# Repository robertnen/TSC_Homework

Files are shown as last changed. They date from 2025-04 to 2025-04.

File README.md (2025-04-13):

### Nenciu George-Robert 333CC

# TSC_Homework
## Schema pe scurt
<div align="center">
  
</div>
<br>

## Imaginea 3D 
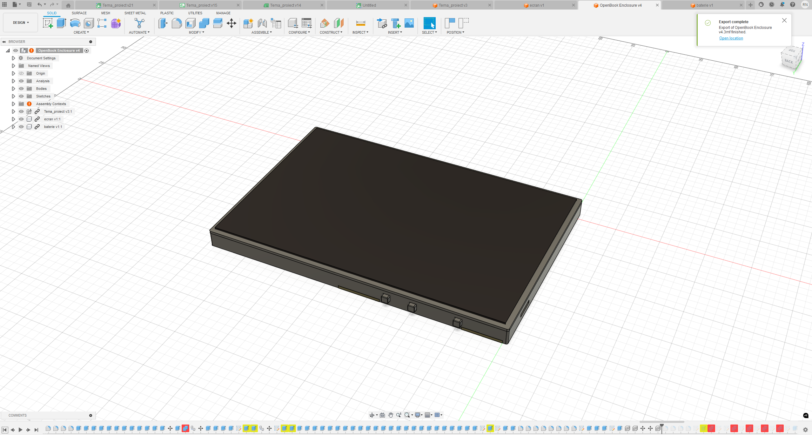
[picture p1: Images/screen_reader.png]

<br>

# Conexiuni Hardware - Proiect ESP32-C6

## ESP32-C6-WROOM-1-N8 (Microcontroler Principal)
- Interfețe disponibile: SPI, I2C, UART, GPIO

---

## BME688 (Senzor Ambiental)
- Interfață: I2C  
- **Pini utilizați**:  
  - SDA → IO21  
  - SCL → IO22

---

## DS3231SN (Real-Time Clock)
- Interfață: I2C (partajat cu BME688)  
- **Pini utilizați**:  
  - SDA → IO21  
  - SCL → IO22  
  - INT_RTC → IO8  
  - 32KHZ → IO1  
  - RTC_RST → IO18

---

## Afișaj E-Ink (7.5 inch)
- Interfață: SPI  
- Rezoluție: 800 x 480 px  
- **Pini utilizați**:  
  - EPD_CS → IO10  
  - EPD_DC → IO5  
  - EPD_RST → IO23  
  - EPD_BUSY → IO3 *(partajat cu MISO)*  
  - MOSI, SCK *(partajate cu SD)*

---

## Modul SD Card
- Interfață: SPI  
- **Pini utilizați**:  
  - SS_SD → IO4  
  - MOSI → IO7  
  - MISO → IO2  
  - SCK → IO6

---

## Memorie Externă Flash (W25Q512JVEIQ, 64MB)
- Interfață: SPI  
- **Pini utilizați**:  
  - FLASH_CS → IO12  
  - MOSI, MISO, SCK *(partajate cu SD)*

---

## Interfață USB/SD
- Funcții: alimentare + date  
- **Pini utilizați**:  
  - USB_D+ → IO13  
  - USB_D- → IO12

---

## Butoane Boot și Reset
- **Pini utilizați**:  
  - IO/BOOT → IO9  
  - RESET → pin dedicat *(conform schemei)*

---

## Sistem de Alimentare și Management
- Baterie Li-Po: 3.7V, 2500mAh  
- **Module și pini**:
  - MCP73831 → încărcare prin USB-C  
  - MAX17048 → monitorizare baterie  
    - SDA → IO21  
    - SCL → IO22  
  - XC6220A331MR-G → 3.3V stabilizat

---

## Conector USB-C
- Funcții: alimentare principală și transfer de date  
- Protejat ESD

---

## Conector Qwiic / Stemma QT
- Interfață: I2C  
- **Pini utilizați**:
  - SDA → IO21  
  - SCL → IO22

<p>ESP32-C6 are un consum de energie optimizat pentru aplicații IoT. În modul activ, consumul variază în funcție de sarcină, dar poate fi redus semnificativ în modurile de repaus profund. De exemplu, în modul Deep Sleep, consumul poate fi de ordinul microamperilor, ceea ce permite o durată de viață extinsă a bateriei.</p>

### Notă privind erorile Airwire / Air Wire

În cadrul designului hardware, anumite erori de tip **Airwire** au fost acceptate intenționat în schema/PCB. Acestea reprezintă conexiuni logice nefinalizate în layout-ul plăcii, dar au fost tolerate în scopuri de testare, dezvoltare rapidă sau în situații unde conexiunile sunt realizate manual (ex: prin fire externe sau jumperi în faza de prototipare). 

Decizia de a le păstra a fost luată pentru a permite flexibilitate în modificări ulterioare și pentru a grăbi ciclul de iterație fără a compromite funcționalitatea de bază a sistemului.

## Alte considerații

<p>În proiectare, s-a ținut cont de recomandările din ghidul de design hardware pentru ESP32-C6 , asigurându-se că traseele PCB pentru interfața I2C sunt cât mai scurte și ecranate corespunzător pentru a minimiza interferențele. De asemenea, s-a acordat atenție alimentării corecte a senzorului BME680, conform specificațiilor acestuia.

Pentru o integrare eficientă a componentelor și optimizarea performanței, s-au urmat recomandările din documentația oficială a ESP32-C6 și a componentelor asociate.</p>

| Componentă | Nr. bucăți | Nume material | Link către datasheet |
|---|---|---|---|
| EAGLE-LTSPICE_C0402 | 26 | Discrete Component | https://eu.mouser.com/datasheet/2/447/KEM_C1023_X7R_AUTO_SMD-3316698.pdf |
| ESP32_WROVER_AVX---SD0805S020S1R0_AVX_SD0805S020S1R0_0 | 2 | Discrete Component | https://eu.mouser.com/datasheet/2/40/AutoMLCCKAM-3216307.pdf |
| ESP32_WROVER_EAGLE-LTSPICE_R0402 | 22 | Discrete Component | https://eu.mouser.com/datasheet/2/54/cr-1858361.pdf |
| TP20R | 17 | Discrete Component | https://www.koaspeer.com/pdfs/RN73R.pdf |
| ESP32_WROVER_SPARKFUN-IC-POWER_SOT23-5 | 1 | Discrete Component | https://eu.mouser.com/datasheet/2/891/Espressif_Systems_ESP32_WROVER_E_L_0-3049094.pdf |
| ADAFRUIT_CHIP-LED0603 | 1 | Discrete Component | https://www.vishay.com/doc?82437 |
| ESP32_WROVER_BME680_PSON80P300X300X100-8N | 1 | Discrete Component | https://eu.mouser.com/datasheet/2/783/BST_BME680_DS001-1509608.pdf |
| ESP32C6_VARISTOR_CT/CN1812 | 1 | Discrete Component | https://product.tdk.com/system/files/dam/doc/product/protection/voltage/varistor_ctvs/data_sheet/75/db/ctvs_14/ct1210s14bautogx1.pdf |
| DIOC1608X36N | 6 | Discrete Component | https://eu.mouser.com/datasheet/2/802/1703143356438-3483895.pdf |
| SOT95P280X120-5N | 1 | Discrete Component | https://www.onsemi.com/PowerSolutions/product.do?id=MC74VHC1GT32P5T5G |
| CAPCP3225X100N | 1 | Discrete Component | https://eu.mouser.com/datasheet/2/18/2/CAP_CACFSBA1-3557832.pdf |
| RCL_CT3528 | 1 | Discrete Component | https://www.vishay.com/doc?20046 |
| ESP32_WROVER_SPARKFUN-DISCRETESEMI_SOT23-3 | 2 | Discrete Component | https://eu.mouser.com/datasheet/2/891/Espressif_Systems_ESP32_WROVER_E_L_0-3049094.pdf |
| SAMACSYS_PARTS_USB4110GFA | 1 | Discrete Component | https://eu.mouser.com/datasheet/2/837/GCT_USB4120-3159195.pdf |
| JST04_1MM_RA | 1 | Discrete Component | https://eu.mouser.com/datasheet/2/564/eCPT-3475515.pdf |
| SOIC127P1032X265-16N | 1 | Discrete Component | https://www.ti.com/lit/ug/sbou289/sbou289.pdf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 |
| XCVR_ESP32-C6-WROOM-1-N8 | 1 | Discrete Component | https://eu.mouser.com/datasheet/2/891/esp32_c6_datasheet_en-3304070.pdf |
| SOT95P280X145-6N | 1 | Discrete Component | https://eu.mouser.com/datasheet/2/414/DIV23-3532318.pdf |
| SOT95P280X125-5N | 1 | Discrete Component | https://eu.mouser.com/datasheet/2/414/DIV23-1551440.pdf |
| FH34SRJ24S05SH99 | 1 | Discrete Component | https://eu.mouser.com/datasheet/2/833/cherry_Rocker_SR_Round_EN-1275415.pdf |
| SON127P600X800X80-9N | 1 | Discrete Component | https://www.ti.com/lit/gpn/tps63710 |
| 16-soldermask | 1 | Steel | https://eu.mouser.com/datasheet/2/58/BPS-DAT-(BB3U)-Datasheet-1282462.pdf |

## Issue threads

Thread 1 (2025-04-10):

Titlul proiectului în schematic depășește chenarul

robertnen, 2025-04-10:
Fișierul cu probleme este:
- [E-Book_v26.sch](https://github.com/stefan-dascalu/Proiect-TSC/blob/main/Hardware/E-Book_v26.sch)

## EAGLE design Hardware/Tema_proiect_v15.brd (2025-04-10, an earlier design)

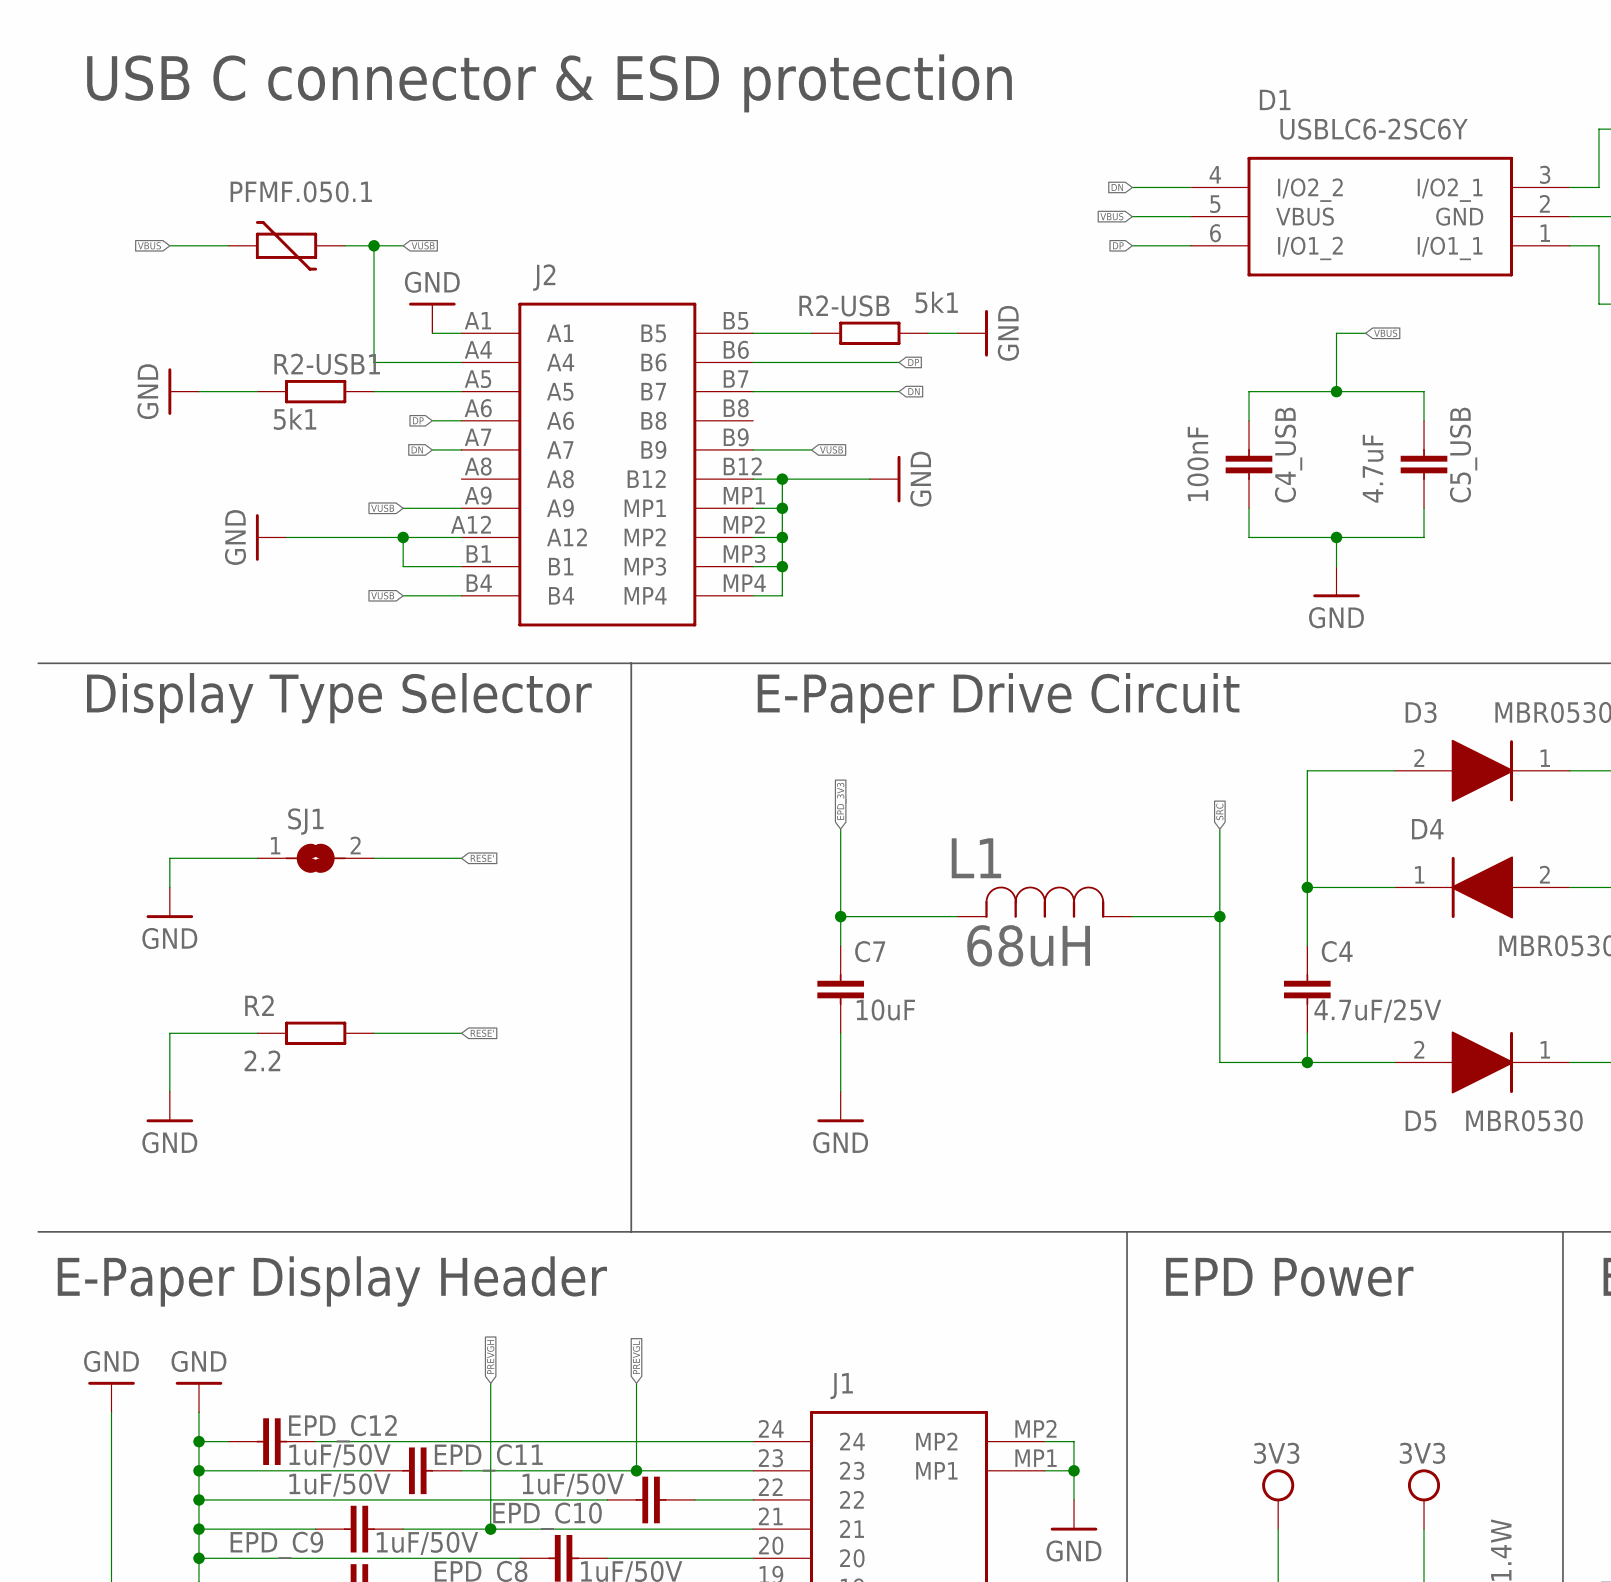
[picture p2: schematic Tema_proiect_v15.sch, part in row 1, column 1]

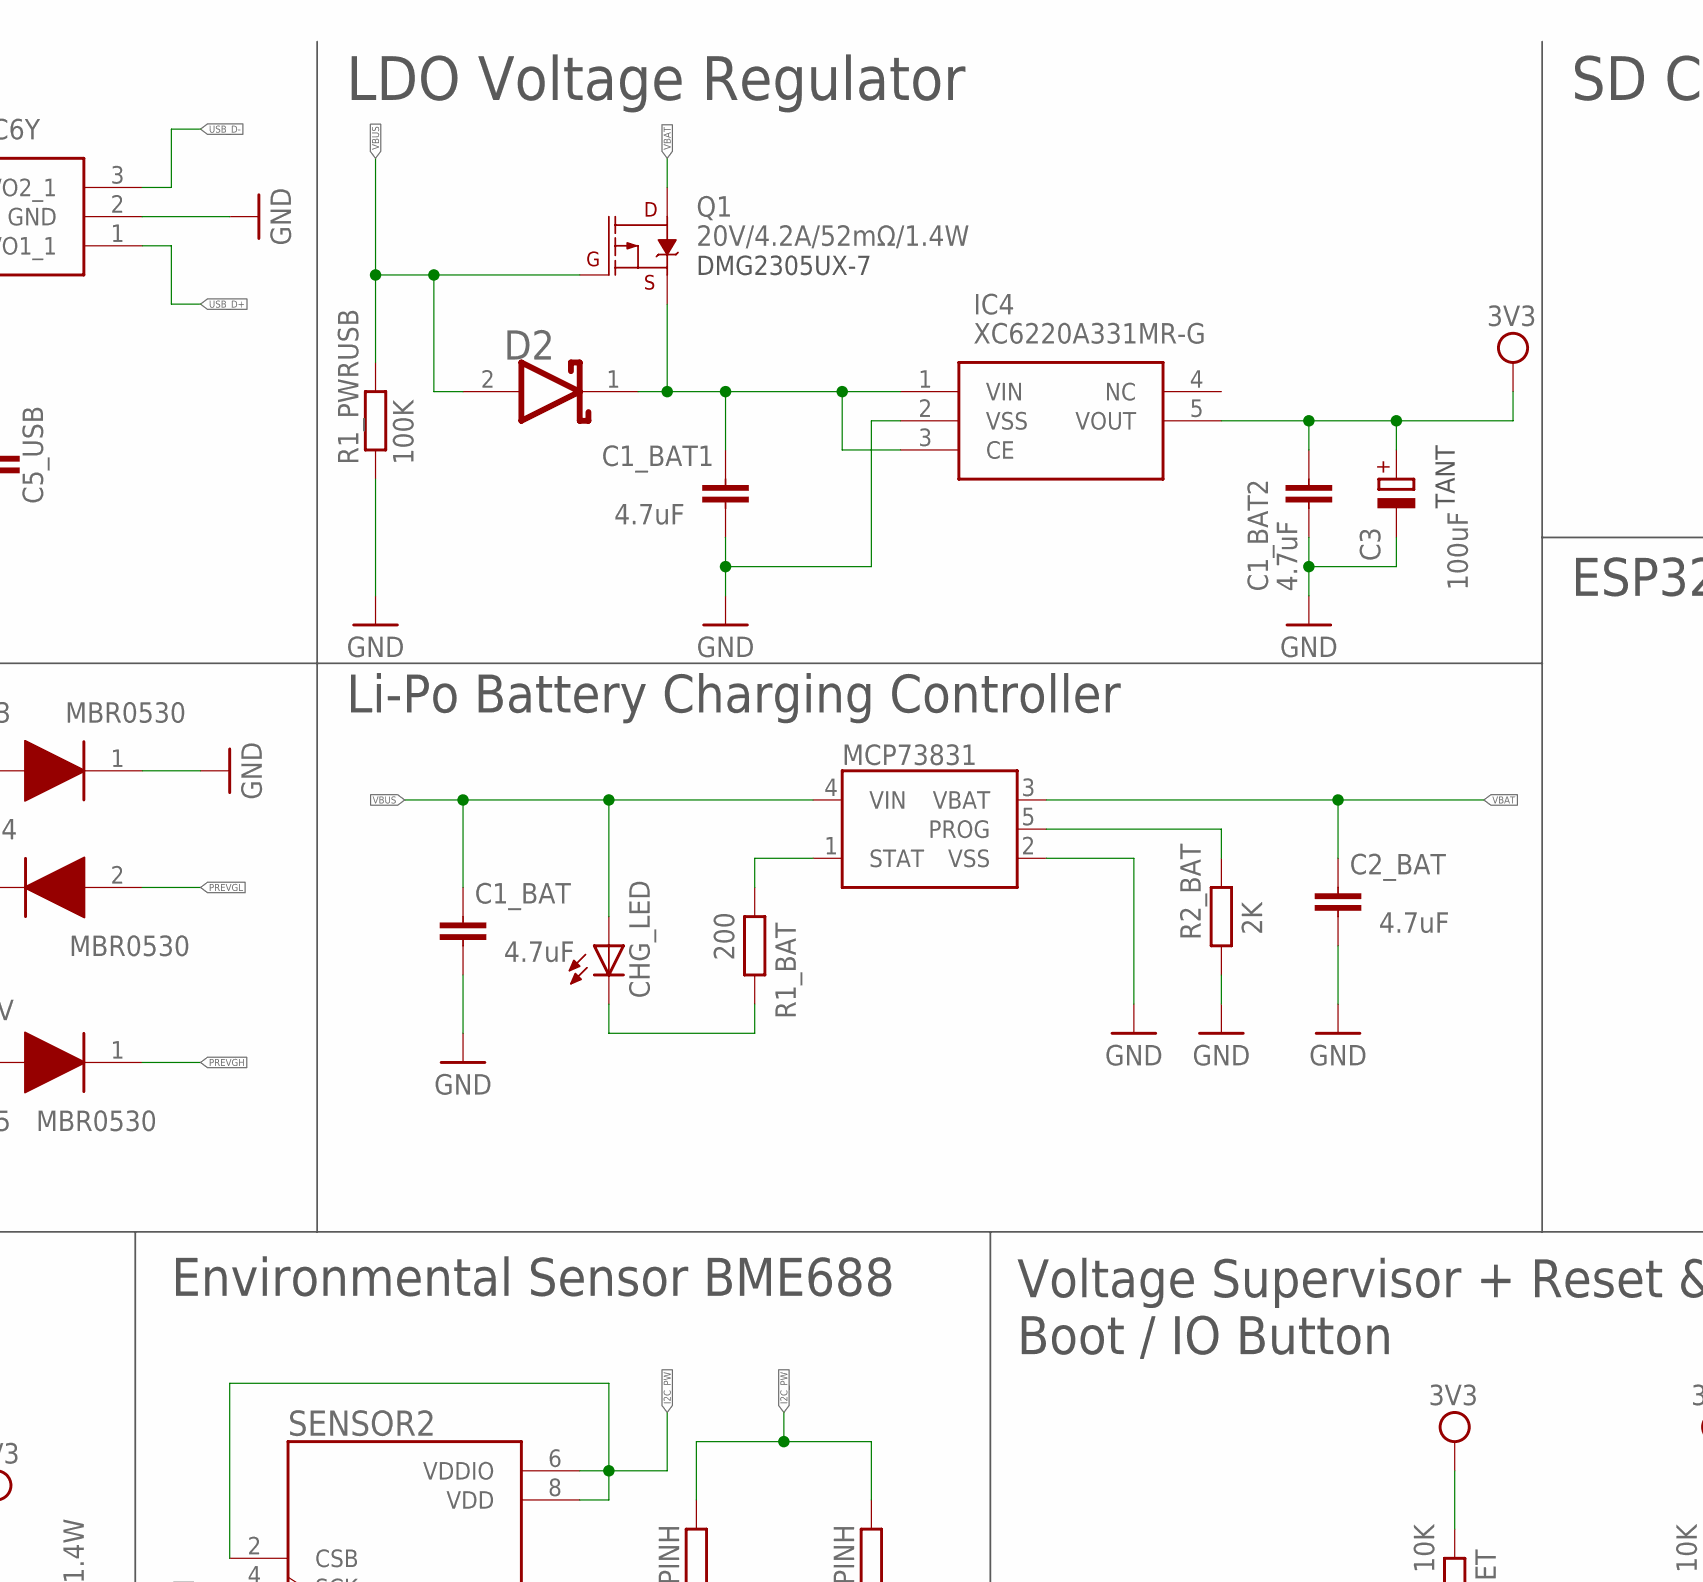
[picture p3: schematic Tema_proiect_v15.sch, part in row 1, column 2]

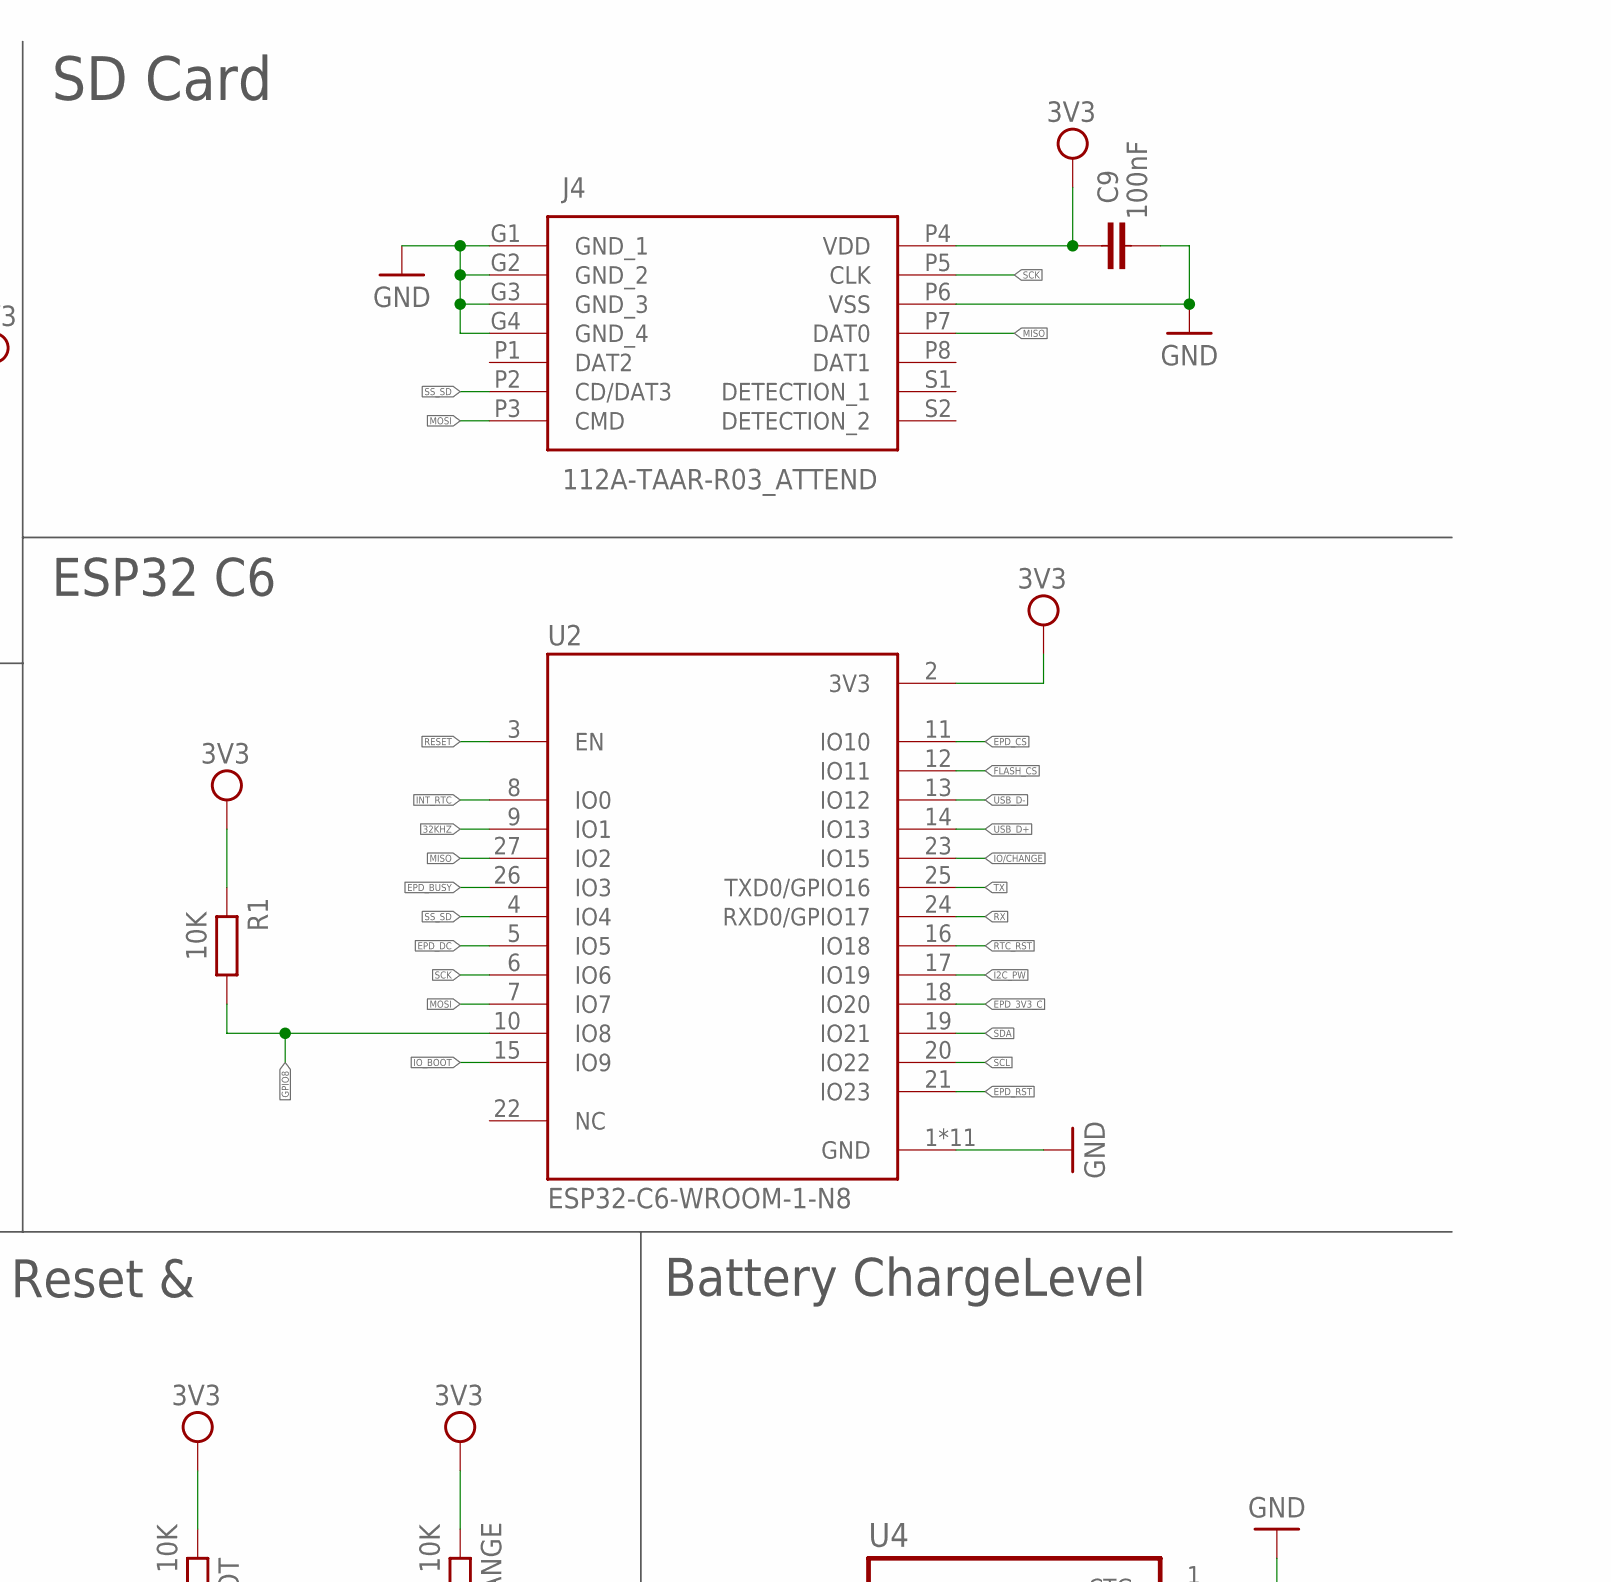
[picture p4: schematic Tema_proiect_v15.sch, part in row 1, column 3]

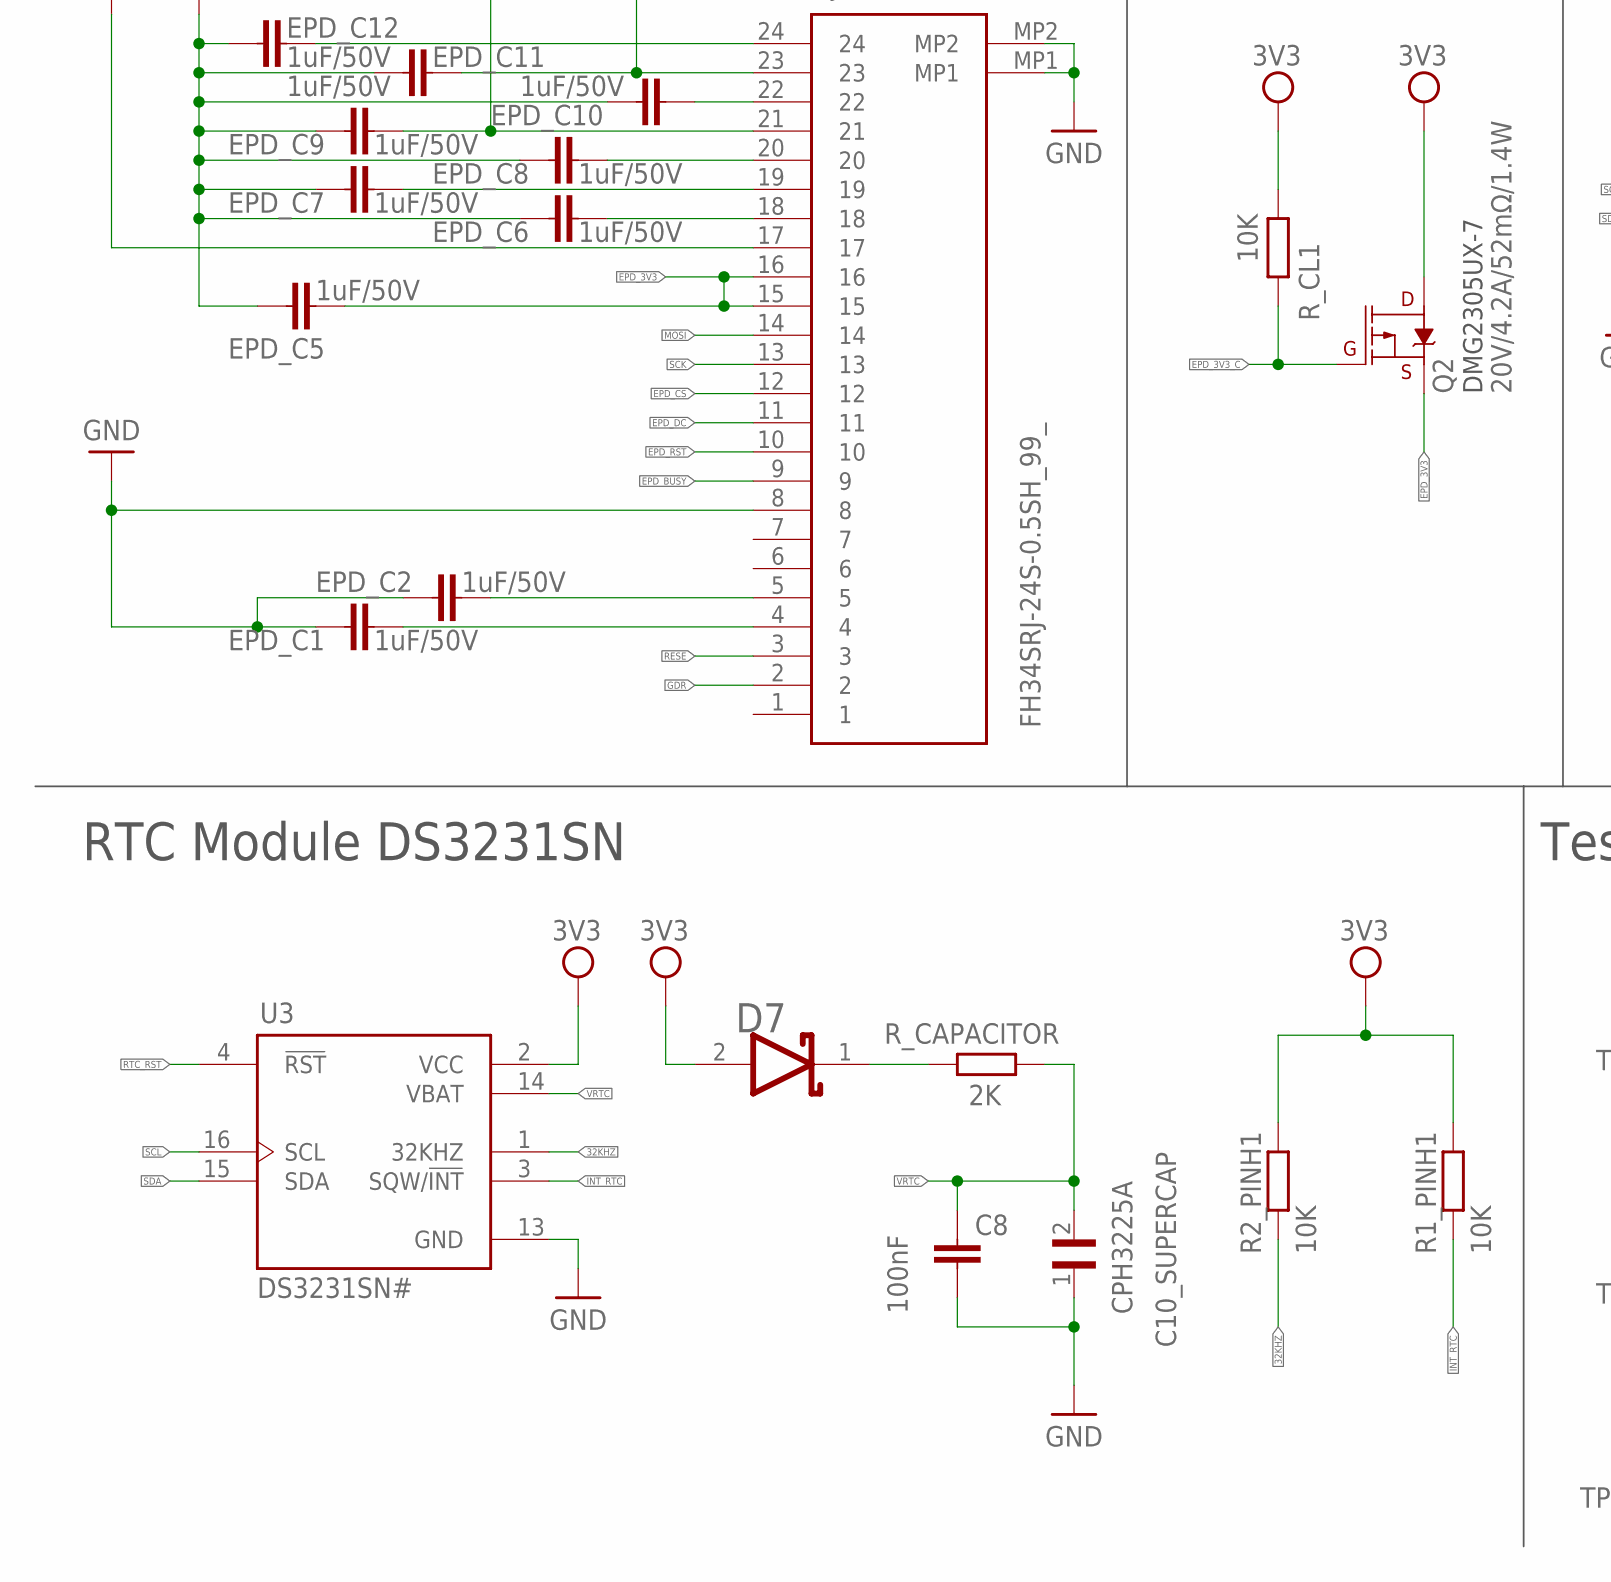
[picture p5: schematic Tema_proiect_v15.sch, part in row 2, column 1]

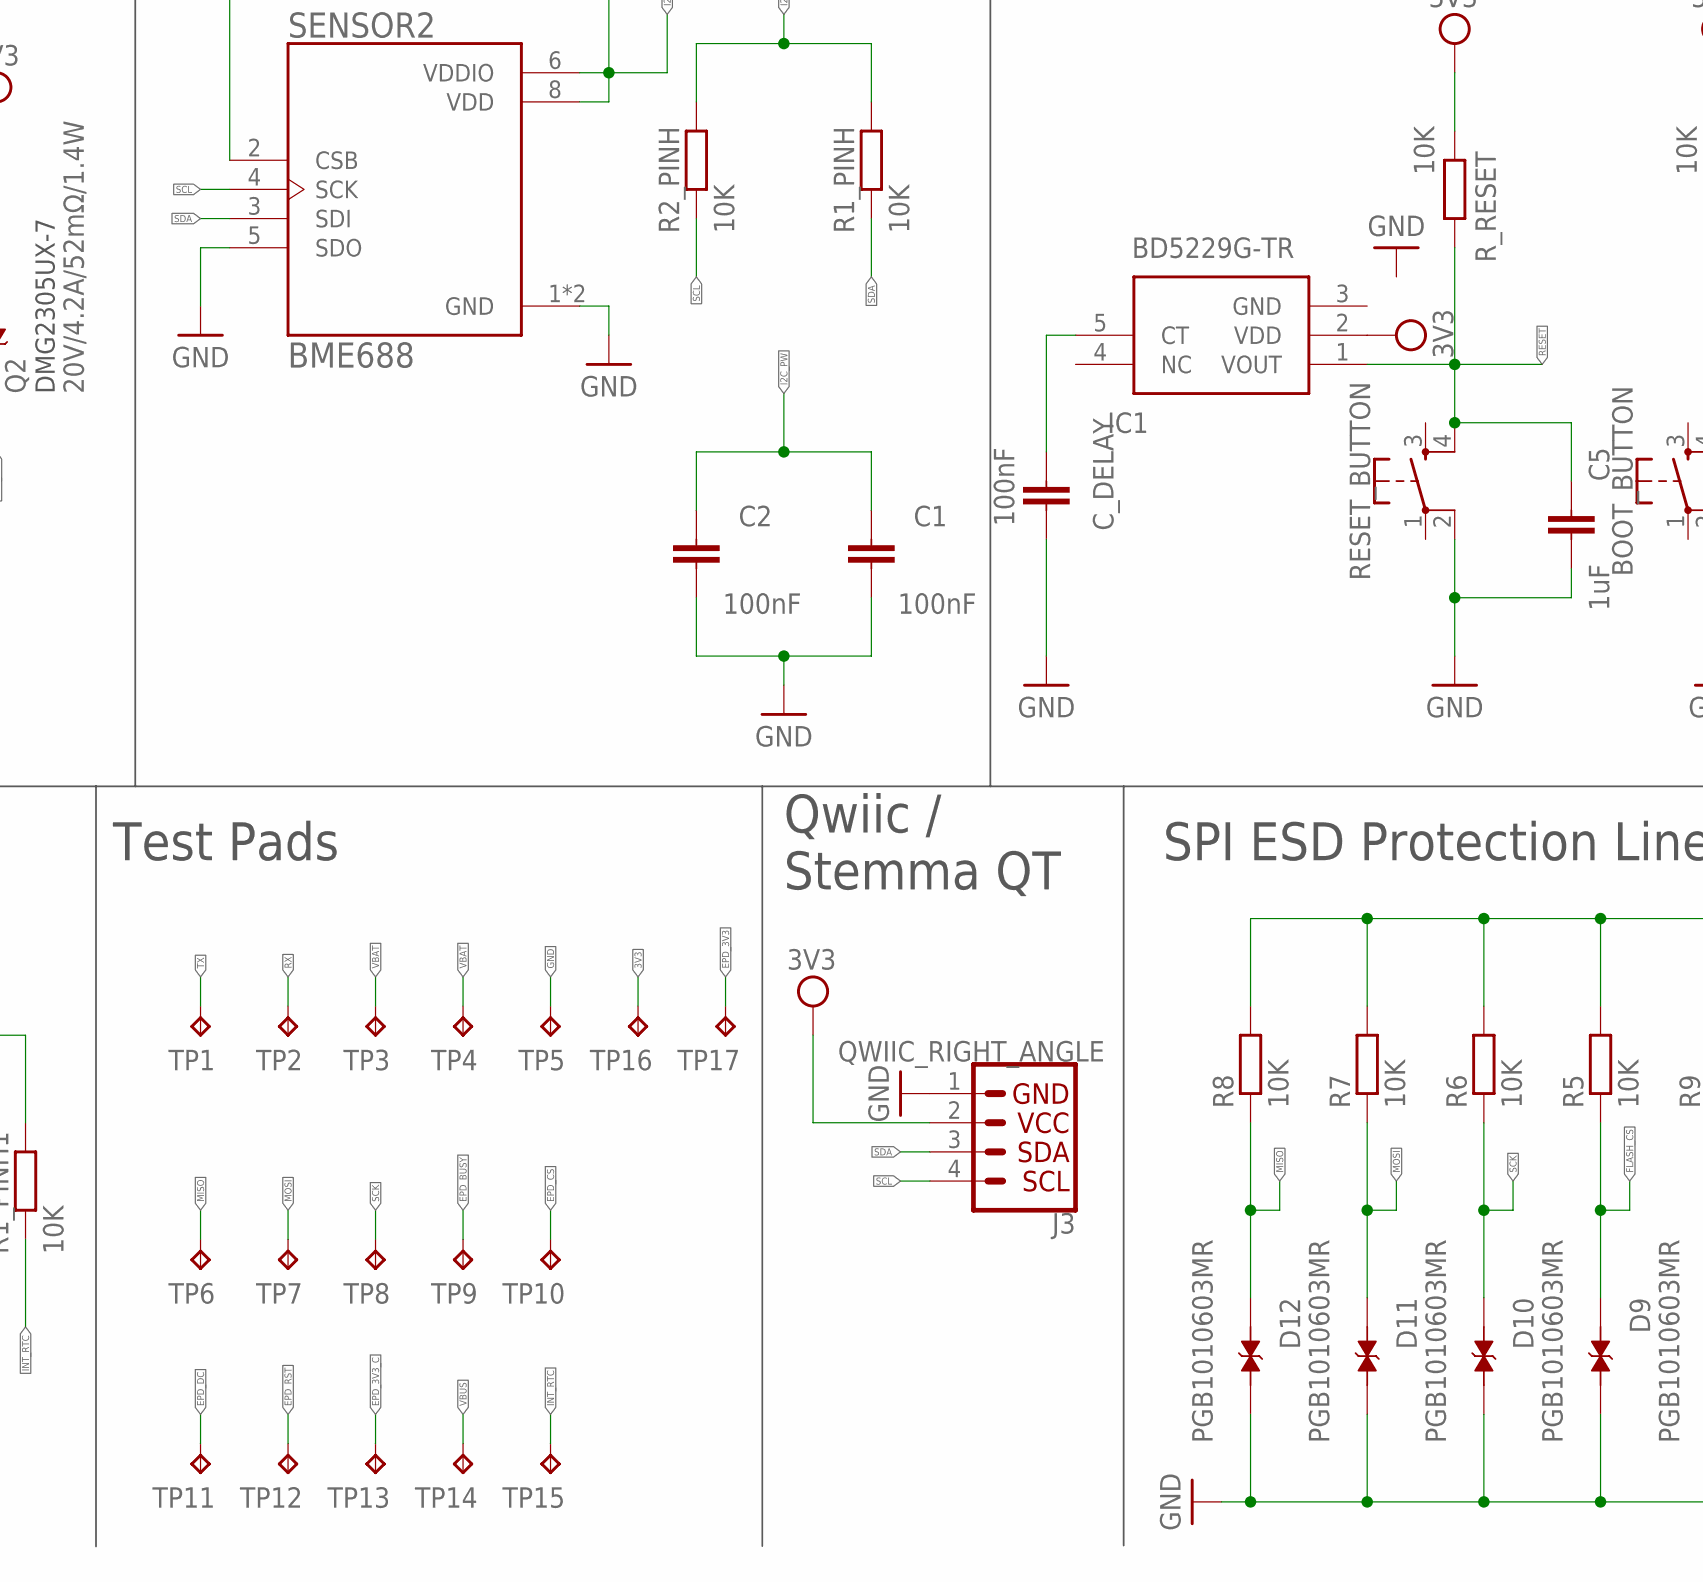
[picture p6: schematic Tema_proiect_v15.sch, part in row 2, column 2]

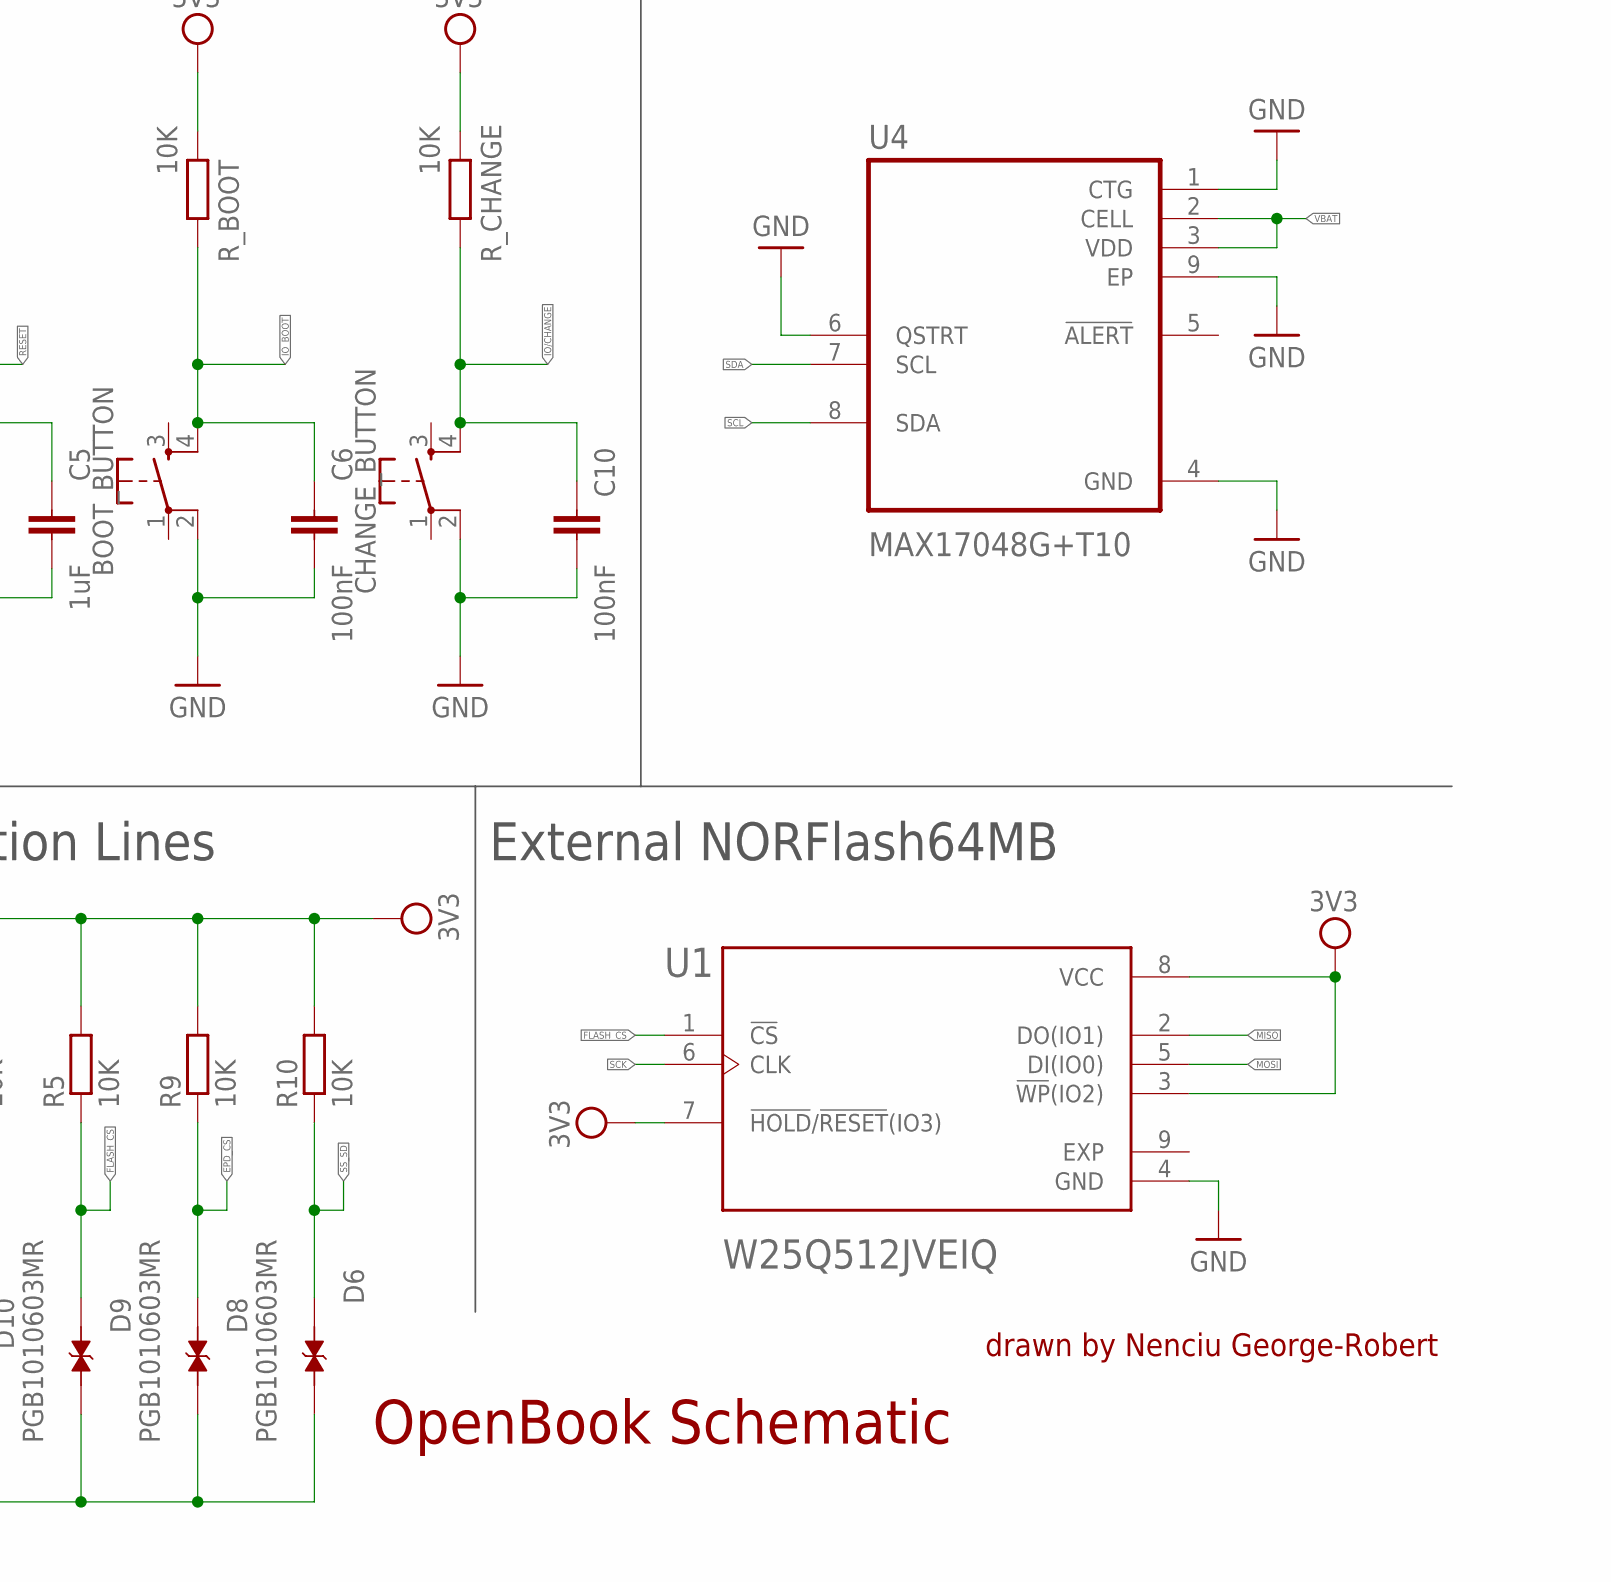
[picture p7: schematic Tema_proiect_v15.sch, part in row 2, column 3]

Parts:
BOOT_BUTTON: BUTTON_CUSYOMV1; MYBUTTON
C1, C2, C4_USB, C6, C8, C9, C10: 100nF; EAGLE-LTSPICE_C0402
C1_BAT, C1_BAT1, C1_BAT2, C2_BAT, C5_USB: 4.7uF; EAGLE-LTSPICE_C0402
C3: 100uF; RCL_CT3528
C4: 4.7uF/25V; EAGLE-LTSPICE_C0402
C5: 1uF; EAGLE-LTSPICE_C0402
C7: 10uF; EAGLE-LTSPICE_C0402
C10_SUPERCAP: CPH3225A; CAPCP3225X100N
CHANGE_BUTTON: BUTTON_CUSYOMV1; MYBUTTON
CHG_LED: ADAFRUIT_LEDCHIP-LED0603; ADAFRUIT_CHIP-LED0603
C_DELAY: 100nF; EAGLE-LTSPICE_C0402
D1: USBLC6-2SC6Y; SOT95P280X145-6N
D2, D7: ESP32_WROVER_AVX---SD0805S020S1R0_AVX_SD0805S020S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; ESP32_WROVER_AVX---SD0805S020S1R0_AVX_SD0805S020S1R0_0
D3, D4, D5: MBR0530; SOD3716X135N
D6, D8, D9, D10, D11, D12: PGB1010603MR; DIOC1608X36N
EPD_C1, EPD_C2, EPD_C5, EPD_C6, EPD_C7, EPD_C8, EPD_C9, EPD_C10, EPD_C11, EPD_C12: 1uF/50V; EAGLE-LTSPICE_C0402
IC1: BD5229G-TR; SOT95P280X125-5N
IC4: XC6220A331MR-G; SOT95P280X120-5N
J1: FH34SRJ-24S-0.5SH_99_; FH34SRJ24S05SH99
J2: SAMACSYS_PARTS_USB4110-GF-A; SAMACSYS_PARTS_USB4110GFA
J3: QWIIC_RIGHT_ANGLE; JST04_1MM_RA
J4: 112A-TAAR-R03_ATTEND; 112ATAARR03ATTEND
L1: 68uH; IND_4828-WE-TPC_WRE
MCP73831: ESP32_WROVER_SPARKFUN-IC-POWER_MCP73831; ESP32_WROVER_SPARKFUN-IC-POWER_SOT23-5
PFMF.050.1: ESP32C6_VARISTORCN1812; ESP32C6_VARISTOR_CT/CN1812
Q1, Q2: 20V/4.2A/52mΩ/1.4W; ESP32_WROVER_SPARKFUN-DISCRETESEMI_SOT23-3
R1, R1_PINH, R1_PINH1, R2_PINH, R2_PINH1, R5, R6, R7, R8, R9, R10: 10K; ESP32_WROVER_EAGLE-LTSPICE_R0402
R1_BAT: 200; ESP32_WROVER_EAGLE-LTSPICE_R0402
R1_PWRUSB: 100K; ESP32_WROVER_EAGLE-LTSPICE_R0402
R2: 2.2; ESP32_WROVER_EAGLE-LTSPICE_R0402
R2-USB, R2-USB1: 5k1; ESP32_WROVER_EAGLE-LTSPICE_R0402
R2_BAT: 2K; ESP32_WROVER_EAGLE-LTSPICE_R0402
RESET_BUTTON: BUTTON_CUSYOMV1; MYBUTTON
R_BOOT: 10K; ESP32_WROVER_EAGLE-LTSPICE_R0402
R_CAPACITOR: 2K; ESP32_WROVER_EAGLE-LTSPICE_R0402
R_CHANGE: 10K; ESP32_WROVER_EAGLE-LTSPICE_R0402
R_CL1: 10K; ESP32_WROVER_EAGLE-LTSPICE_R0402
R_RESET: 10K; ESP32_WROVER_EAGLE-LTSPICE_R0402
SENSOR2: BME688; ESP32_WROVER_BME680_PSON80P300X300X100-8N
SJ1: SJ
TP1, TP2, TP3, TP4, TP5, TP6, TP7, TP8, TP9, TP10, TP11, TP12, TP13, TP14, TP15, TP16, TP17: TPTP20R; TP20R
U1: W25Q512JVEIQ; SON127P600X800X80-9N
U2: ESP32-C6-WROOM-1-N8; XCVR_ESP32-C6-WROOM-1-N8
U3: DS3231SN#; SOIC127P1032X265-16N
U4: MAX17048G+T10; SON50P200X200X80-9N

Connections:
3V3: C1_BAT2.1, C3.+, C9.1, D7.2 (ANODE), IC1.2 (VDD), IC4.5 (VOUT), J3.2, J4.P4 (VDD), Q2.3 (D), R1.2, R1_PINH1.2, R2_PINH1.2, R5.2, R6.2, R7.2, R8.2, R9.2, R10.2, R_BOOT.2, R_CHANGE.2, R_CL1.2, R_RESET.2, TP16.TP, U1.3 (!WP!(IO2)), U1.7 (!HOLD!/!RESET!(IO3)), U1.8 (VCC), U2.2 (3V3), U3.2 (VCC)
32KHZ: R2_PINH1.1, U2.9 (IO1), U3.1 (32KHZ)
DN: D1.4 (I/O2_2), J2.A7, J2.B7
DP: D1.6 (I/O1_2), J2.A6, J2.B6
EPD_3V3: C7.1, L1.2, Q2.2 (S), TP17.TP
EPD_3V3_C: TP13.TP, U2.18 (IO20)
EPD_BUSY: J1.9, TP9.TP, U2.26 (IO3)
EPD_CS: D8.1, J1.12, R9.1, TP10.TP, U2.11 (IO10)
EPD_DC: J1.11, TP11.TP, U2.5 (IO5)
EPD_RST: J1.10, TP12.TP, U2.21 (IO23)
FLASH_CS: D9.1, R5.1, U1.1 (!CS), U2.12 (IO11)
GDR: J1.2
GND: BOOT_BUTTON.2, C1.2, C1_BAT.2, C1_BAT1.2, C1_BAT2.2, C2.2, C2_BAT.2, C3.-, C4_USB.2, C5.2, C5_USB.2, C6.2, C7.2, C8.2, C9.2, C10.2, C10_SUPERCAP.1, CHANGE_BUTTON.2, C_DELAY.2, D1.2 (GND), D3.1 (K), D6.2, D8.2, D9.2, D10.2, D11.2, D12.2, EPD_C1.1, EPD_C2.1, EPD_C5.1, EPD_C6.1, EPD_C7.1, EPD_C8.1, EPD_C9.1, EPD_C10.1, EPD_C11.1, EPD_C12.1, IC4.2 (VSS), J1.8, J1.17, J1.MP1, J1.MP2, J2.A1, J2.A12, J2.B1, J2.B12, J2.MP1, J2.MP2, J2.MP3, J2.MP4, J3.1, J4.G1 (GND_1), J4.G2 (GND_2), J4.G3 (GND_3), J4.G4 (GND_4), J4.P6 (VSS), MCP73831.2 (VSS), R1_PWRUSB.1, R2.1, R2-USB.2, R2-USB1.1, R2_BAT.2, RESET_BUTTON.2, SENSOR2.1 (GND), SENSOR2.5 (SDO), SENSOR2.7 (GND), SJ1.1, TP5.TP, U1.4 (GND), U2.1 (GND), U2.28 (GND), U2.29_1 (GND), U2.29_2 (GND), U2.29_3 (GND), U2.29_4 (GND), U2.29_5 (GND), U2.29_6 (GND), U2.29_7 (GND), U2.29_8 (GND), U2.29_9 (GND), U3.13 (GND), U4.1 (CTG), U4.4 (GND), U4.6 (QSTRT), U4.9 (EP)
GPIO8: R1.1, U2.10 (IO8)
I2C_PW: U2.17 (IO19)
INT_RTC: R1_PINH1.1, TP15.TP, U2.8 (IO0), U3.3 (SQW/!INT)
IO/CHANGE: U2.23 (IO15)
IO_BOOT: U2.15 (IO9)
MISO: D12.1, J4.P7 (DAT0), R8.1, TP6.TP, U1.2 (DO(IO1)), U2.27 (IO2)
MOSI: D11.1, J1.14, J4.P3 (CMD), R7.1, TP7.TP, U1.5 (DI(IO0)), U2.7 (IO7)
unnamed: J2.A5, R2-USB1.2
unnamed: J2.B5, R2-USB.1
unnamed: C1_BAT1.1, D2.1 (CATHODE), IC4.1 (VIN), IC4.3 (CE), Q1.2 (S)
unnamed: C4.1, D3.2 (A), D4.1 (K)
unnamed: MCP73831.1 (STAT), R1_BAT.2
unnamed: CHG_LED.C, R1_BAT.1
unnamed: MCP73831.5 (PROG), R2_BAT.1
unnamed: EPD_C12.2, J1.24
unnamed: EPD_C11.2, J1.23
unnamed: EPD_C10.2, J1.22
unnamed: EPD_C9.2, J1.21
unnamed: EPD_C8.2, J1.20
unnamed: EPD_C7.2, J1.19
unnamed: EPD_C6.2, J1.18
unnamed: EPD_C5.2, J1.15, J1.16
unnamed: EPD_C2.2, J1.5
unnamed: EPD_C1.2, J1.4
unnamed: Q2.1 (G), R_CL1.1
unnamed: R1_PINH.2, R2_PINH.2
unnamed: SENSOR2.2 (CSB), SENSOR2.6 (VDDIO), SENSOR2.8 (VDD)
unnamed: C1.1, C2.1
unnamed: C5.1, IC1.1 (VOUT), RESET_BUTTON.4, R_RESET.1
unnamed: BOOT_BUTTON.4, C6.1, R_BOOT.1
unnamed: C10.1, CHANGE_BUTTON.4, R_CHANGE.1
unnamed: C_DELAY.1, IC1.5 (CT)
unnamed: D7.1 (CATHODE), R_CAPACITOR.2
unnamed: C8.1, C10_SUPERCAP.2, R_CAPACITOR.1
PREVGH: D5.1 (K)
PREVGL: D4.2 (A)
RESE: J1.3
RESE': R2.2, SJ1.2
RESET: U2.3 (EN)
RTC_RST: U2.16 (IO18), U3.4 (!RST)
RX: TP2.TP, U2.24 (RXD0/GPIO17)
SCK: D10.1, J1.13, J4.P5 (CLK), R6.1, TP8.TP, U1.6 (CLK), U2.6 (IO6)
SCL: J3.4, R2_PINH.1, SENSOR2.4 (SCK), U2.20 (IO22), U3.16 (SCL), U4.8 (SDA)
SDA: J3.3, R1_PINH.1, SENSOR2.3 (SDI), U2.19 (IO21), U3.15 (SDA), U4.7 (SCL)
SRC: C4.2, D5.2 (A), L1.1
SS_SD: D6.1, J4.P2 (CD/DAT3), R10.1, U2.4 (IO4)
TX: TP1.TP, U2.25 (TXD0/GPIO16)
USB_D+: D1.1 (I/O1_1), U2.14 (IO13)
USB_D-: D1.3 (I/O2_1), U2.13 (IO12)
VBAT: C2_BAT.1, MCP73831.3 (VBAT), Q1.3 (D), TP3.TP, TP4.TP, U4.2 (CELL), U4.3 (VDD)
VBUS: C1_BAT.1, C4_USB.1, C5_USB.1, CHG_LED.A, D1.5 (VBUS), D2.2 (ANODE), MCP73831.4 (VIN), PFMF.050.1.2, Q1.1 (G), R1_PWRUSB.2, TP14.TP
VRTC: U3.14 (VBAT)
VUSB: J2.A4, J2.A9, J2.B4, J2.B9, PFMF.050.1.1

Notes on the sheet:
USB C connector & ESD protection
DMG2305UX-7
TANT
LDO Voltage Regulator
SD Card
Display Type Selector
E-Paper Drive Circuit
Li-Po Battery Charging Controller
ESP32 C6
E-Paper Display Header
EPD Power
Environmental Sensor BME688
Voltage Supervisor + Reset & Boot / IO Button
Battery ChargeLevel
RTC Module DS3231SN
Test Pads
Qwiic / Stemma QT
SPI ESD Protection Lines
External NORFlash64MB
OpenBook Schematic
drawn by Nenciu George-Robert

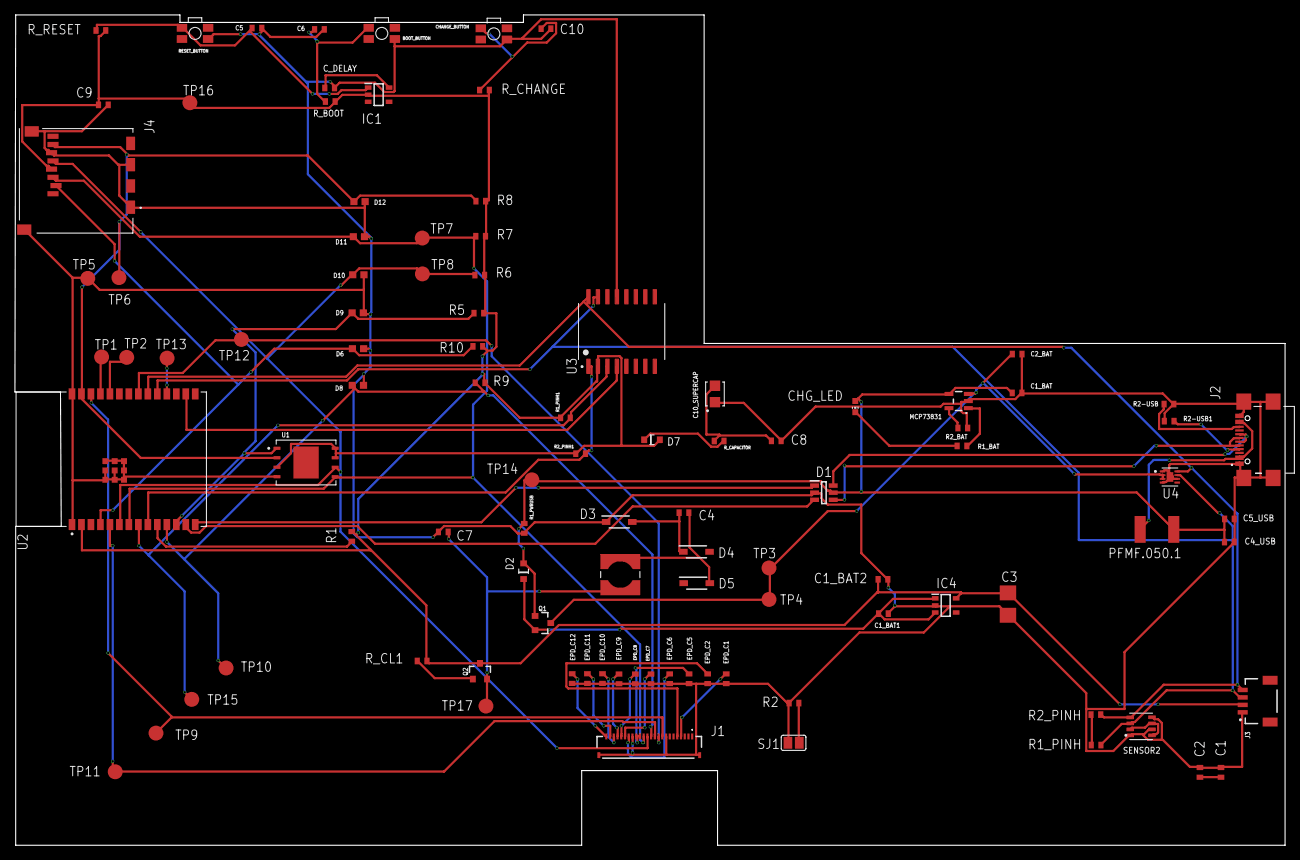
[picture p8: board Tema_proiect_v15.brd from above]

Board: 2 copper layers, 170.1 x 111.2 mm, 100 parts (0 on the bottom side), 57 nets.

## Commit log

2025-04-04 Added homework
    [OpenBook Enclosure v4.3mf, Tema_proiect v14.brd, Tema_proiect_v15.sch]
2025-04-05 Create OpenBook Enclosure v4.step

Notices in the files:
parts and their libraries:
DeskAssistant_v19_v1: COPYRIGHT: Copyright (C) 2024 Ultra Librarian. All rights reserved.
